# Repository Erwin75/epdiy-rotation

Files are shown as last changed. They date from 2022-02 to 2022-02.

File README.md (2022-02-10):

  

EPDiy E-Paper Driver
=======================================

EPDiy is a driver board which talks to affordable E-Paper (or E-Ink) screens, which are usually sold as replacement screens for E-Book readers. Why are they interesting?

* Easy on the eyes and paper-like aesthetics
* No power consumption when not updating
* Sunlight-readable

Ready-made DIY modules for this size and with 4bpp (16 Grayscale) color support are currently quite expensive. This project uses Kindle replacement screens, which are available for 20$ (small) / 30$ (large) on ebay!

The EPDiy driver board targets multiple E-Paper displays. As the driving method for all matrix-based E-ink displays seems to be more or less the same, only the right connector and timings are needed. The EPDiy PCB v5 features 33pin, 34pin and a 39pin connectors, which allow to drive the following display types: ED097OC4, ED060SC4, ED097TC2, ED060SC7. For the full list of supported displays, refer to the table below.

Revision 5 of the board is optimized for the use with LiPo batteries, featuring a LiPo charger and ultra-low deep sleep current.

This project supports a driver for the ESP-IDF and Arduino. For installation instructions, please refer to the [documentation](https://epdiy.readthedocs.io/en/latest/getting_started.html#getting-your-board).

Building It
-----------

If you want to build a board right now, there are two possible routes:

 - Use the new v6 PCB (`hardware/epaper-breakout/gerbers_v6.zip`). 
   **So far, I only tested a prototype of it. The gerbers only contain fixes for powering from battery, but have not yet been ordered with.**
   **If you have tested them, please let me know!**
   The BOM is available at (`hardware/epaper-breakout/BOM.csv`).
   Positioning files for SMT assembly are available at (`hardware/epaper-breakout/gerbers/epaper-breakout-top-pos.csv`). 
   Please double check the part positioning and Rotation with your assembly service!
   More information on the order process and where to find parts is in the [documentation](https://epdiy.readthedocs.io/en/latest/getting_started.html#getting-your-board).
 
   Make sure to select the `V6` board revision in `idf.py menuconfig` when building the examples.
 
 - Use the old v5 PCB (`hardware/epaper-breakout/gerbers_v5.zip`).  
   This is the last board using the LT1945 booster.
   Make sure to select the `V5` board revision in `idf.py menuconfig` when building the examples.

Gettings Started
----------------

For instructions and more information visit the [documentation](https://epdiy.readthedocs.io/en/latest/getting_started.html)!

Join the Discussion
----------------

 -  Matrix Community: +epdiy:matrix.vroland.de
 - Slack: See badge
Displays
--------

|Name|Size|Resolution|Compatible|Connector|Pin count|Compatible since pcb version|Notes
| --: | --: | --: | --: | --: | --: |--: |--: |
|ED060SC4|6"|800 x 600|yes, tested|FH26W-39S-0.3SHW(60)|39|v2|
|ED097OC4|9.7"|1200 x 825|yes, tested|XF2M-3315-1A|33|V2|Cheap, inferior contrast
|ED097TC2|9.7"|1200 x 825|yes, tested|XF2M-3315-1A|33|V2|Slightly higher price, better contrast
|ED097OC1|9.7"|1200 x 825|yes (should work)|XF2M-3315-1A|33|V2|Cheap, inferior performance
|ED047TC1|4.7"|960 x 540|yes, tested|40-pin|40|LILYGO 4.7" EPD|Supported only by 4.7" e-paper board by LILYGO
|ED052TC2|5.2"|960 x 540|yes, tested|40-pin|40|LILYGO 4.7" EPD|Supported only by 4.7" e-paper board by LILYGO
| ED050SC5 | 5" | 600 x 800 | yes, tested | THD0510-33CL-GF | 33 | v5 | 
| ED050SC3 | 5" | 600 x 800 | yes (should work) | THD0510-33CL-GF | 33 | v5 | 
|ED133UT2|13.3"|1600 x 1200|yes, tested|adapter board|39|V2|Adapter Board required, also PENG133D
|ED060XC3|6"|758 x 1024|yes, tested|THD0515-34CL-SN|34|V5|Cheapest, good contrast and resolution
|ED060XD4|6"|758 x 1024|yes, tested|THD0515-34CL-SN|34|V5|
|ED060XC5|6"|758 x 1024|yes (should work as ED060XC3)|THD0515-34CL-SN|34|V5|
|ED060XD6|6"|758 x 1024|yes (should work as ED060XC3)|THD0515-34CL-SN|34|V5|
|ED060XH2|6"|758 x 1024|yes (should work as ED060XC3)|THD0515-34CL-SN|34|V5|
|ED060XC9|6"|758 x 1024|yes (should work as ED060XC3)|THD0515-34CL-SN|34|V5|
|ED060KD1|6"|1072 x 1448|yes (should work as ED060XC3)|THD0515-34CL-SN|34|V5|
|ED060KC1|6"|1072 x 1448|yes (should work as ED060XC3)|THD0515-34CL-SN|34|V5|
|ED060SCF|6"|600 x 800|yes, tested|THD0515-34CL-SN|34|V5|Different flex cable shape
|ED060SCN|6"|600 x 800|yes (should work as ED060XC3)|THD0515-34CL-SN|34|V5|Different flex cable shape
|ED060SCP|6"|600 x 800|yes (should work as ED060XC3)|THD0515-34CL-SN|34|V5|Different flex cable shape
| ED060SC7 | 6" | 600 x 800 | yes (should work) | AXT334124 | 34 | v5 |connector dropped in v6
| ED060SCG | 6" | 600 x 800 | yes (should work) | AXT334124 | 34 | v5 |connector dropped in v6
| ED060SCE | 6" | 600 x 800 | yes (should work) | AXT334124 | 34 | v5 |connector dropped in v6
| ED060SCM | 6" | 600 x 800 | yes (should work) | AXT334124 | 34 | v5 |connector dropped in v6
| ED060SCT | 6" | 600 x 800 | yes, tested | AXT334124 | 34 | v5 |connector dropped in v6

Troubleshooting
---------------

The following list is compiled from past experiences and GitHub issues:
 * **The displayed image displays only part of the image.** Make sure to select the correct display type as described [here](https://epdiy.readthedocs.io/en/latest/getting_started.html#selecting-a-display-type).
 * **The existing image fades / darkens when updating a partial screen region.** Make sure the VCOM voltage is [calibrated](https://epdiy.readthedocs.io/en/latest/getting_started.html#calibrate-vcom) for your specific display.
 * **The second third of the image is replaced with the last third.** This seems to be a timing issue we could not yet quite figure out the reason for. For a workarround or suggestions please [join the discussion](https://github.com/vroland/epdiy/issues/15).
 * **The ESP does not boot correctly when external periperals are connected.** Make sure not to pull GPIO12 high during boot, as it is a strapping pin internal voltage selection (https://github.com/vroland/epdiy/issues/17).
 
More on E-Paper Displays
------------------------

 * List of E-Paper devices and their screens: https://e-ink-reader.ru/chg_dsp_en.php (thanks, @mcer12)
 * Reverse engineering of display pins, possible starting point for alternative drivers: https://linux-sunxi.org/PocketBook_Touch_Lux_3 (thanks, @mcer12)
 * Reverse engineering and explanation on driving EPDs: http://essentialscrap.com/eink/index.html
 * Earlier take on driving 6" EPDs with an ESP32, basis of original power circuit: http://spritesmods.com/?art=einkdisplay&page=1
 * Related Hackaday projects: https://hackaday.io/project/21607 https://hackaday.io/project/11537

If you know any other useful resources or have suggestions, please comment on #31!

Hackaday Project
----------------

For more details, see the project page on Hackaday: https://hackaday.io/project/168193-epdiy-976-e-paper-controller

demo image
board front

Licenses
--------

The weather example is Copyright (c) David Bird 2018 (except for minor modifications). Please refer to `examples/weather/README.md` for details.

The board and schematic are licensed under a  <a rel="license" href="https://creativecommons.org/licenses/by-sa/4.0/">Creative Commons Attribution-ShareAlike 4.0 International License</a>.

Firmware and remaining examples are licensed under the terms of the GNU GPL version 3.
Utilities are licensed under the terms of the MIT license.

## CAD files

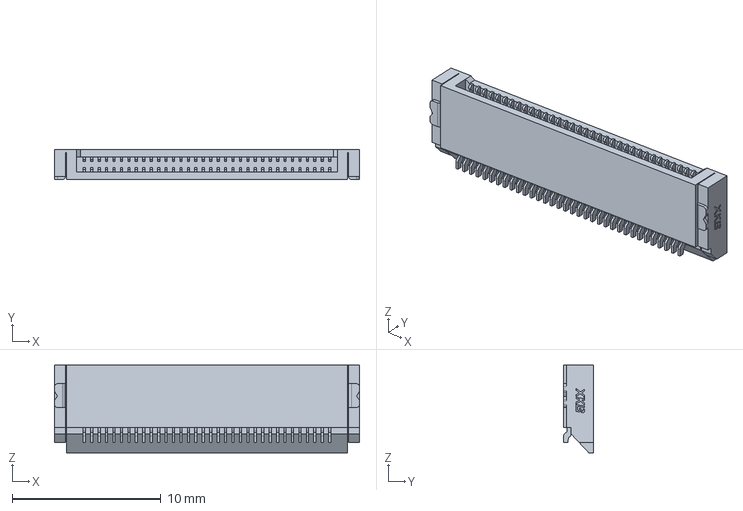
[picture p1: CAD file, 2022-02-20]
hardware/epaper-breakout/3dmodels/x05a20h34x_FPC.stp
20.5 x 2.00 x 5.90 mm

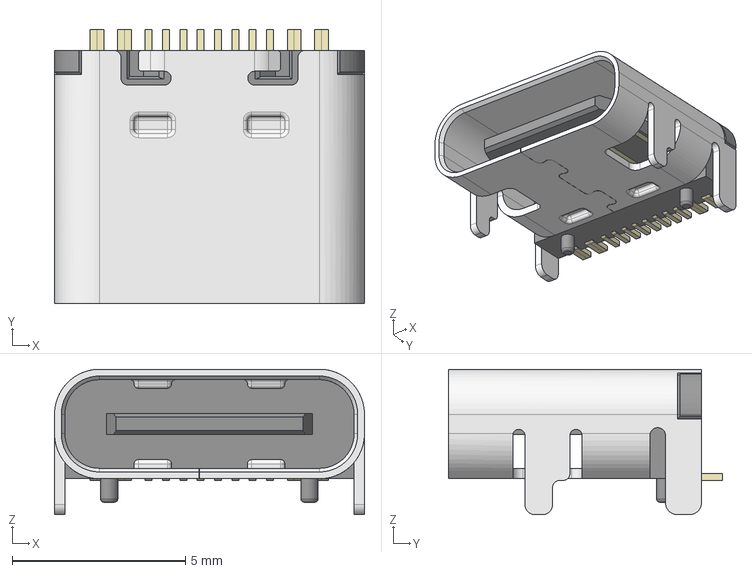
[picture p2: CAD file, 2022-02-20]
hardware/epaper-breakout/3dmodels/HRO_TYPE-C-31-M-12.step
8.95 x 7.90 x 4.20 mm

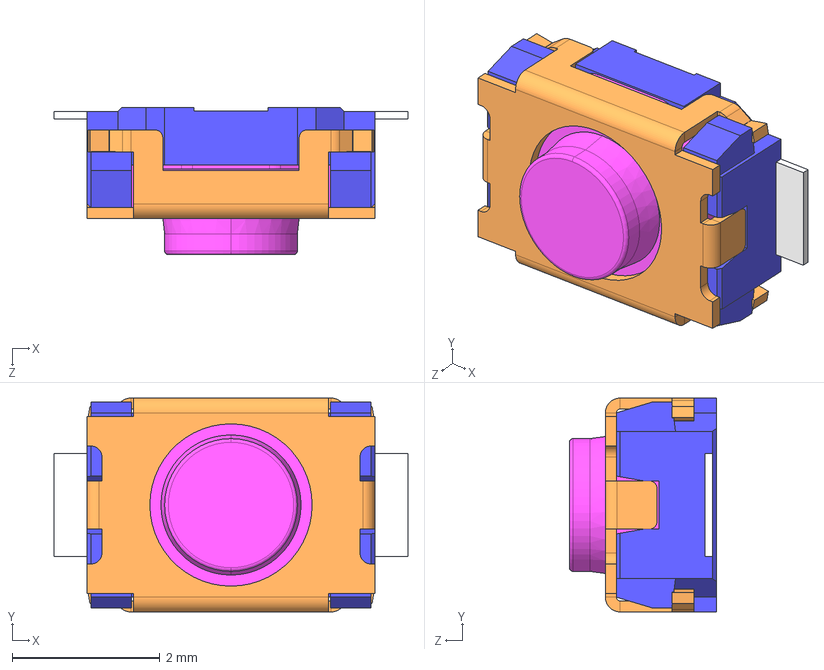
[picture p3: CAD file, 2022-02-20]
hardware/epaper-breakout/3dmodels/SKRKAH.STEP
4.80 x 2.90 x 2.00 mm

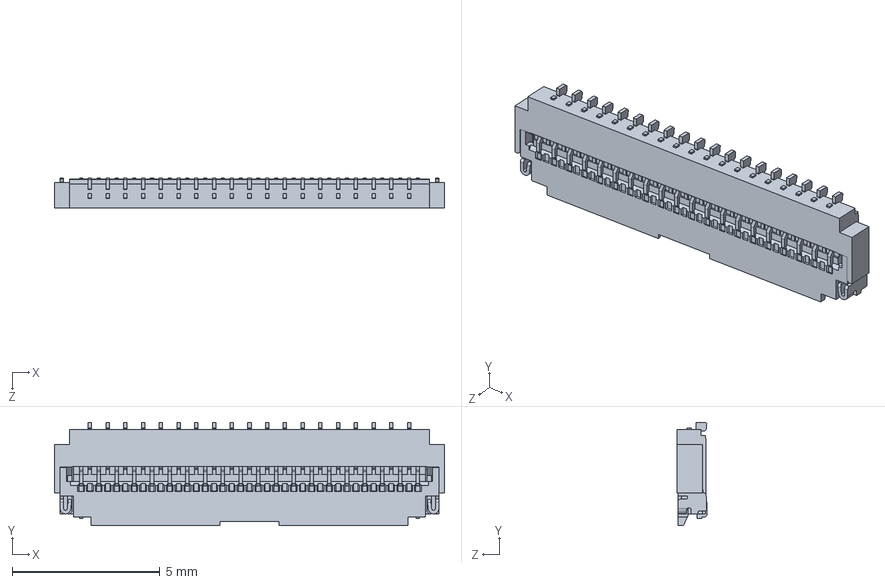
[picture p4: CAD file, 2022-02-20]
hardware/epaper-breakout/3dmodels/Hirose_39pin_FPC.STEP
13.2 x 3.50 x 1.00 mm

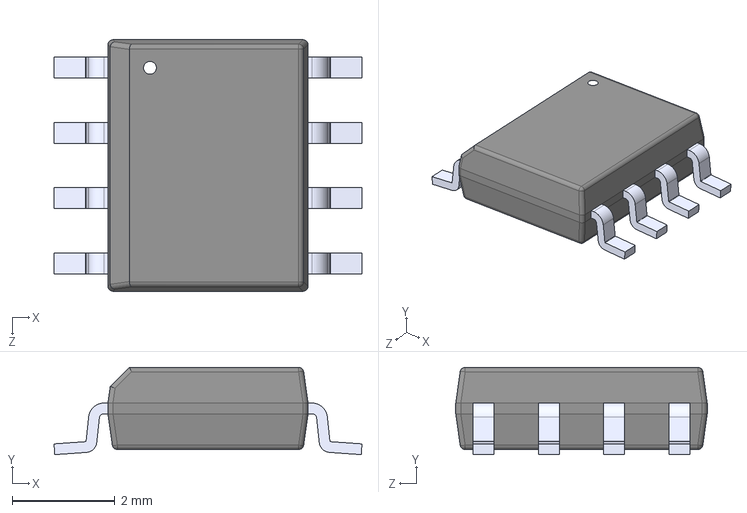
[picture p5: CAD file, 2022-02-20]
hardware/epaper-breakout/3dmodels/TP4056.step
6.00 x 1.70 x 4.90 mm

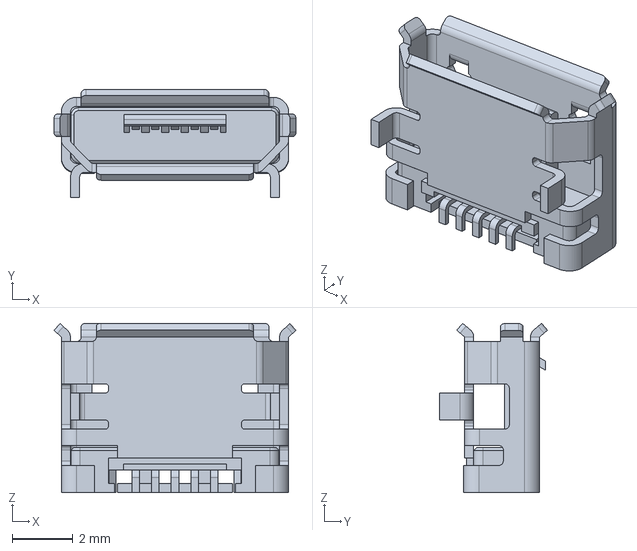
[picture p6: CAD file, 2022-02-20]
hardware/epaper-breakout/3dmodels/MicroUSB-2013499-1-f-3d.stp
8.00 x 3.57 x 5.60 mm

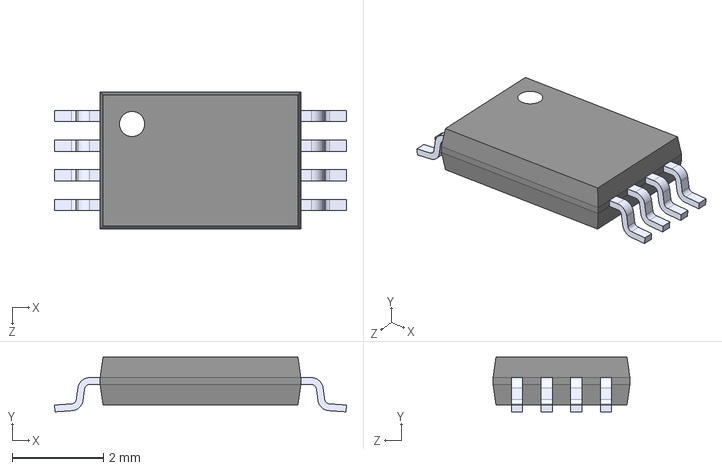
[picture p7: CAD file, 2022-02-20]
hardware/epaper-breakout/3dmodels/tps2113apwr.step
6.40 x 1.20 x 3.00 mm

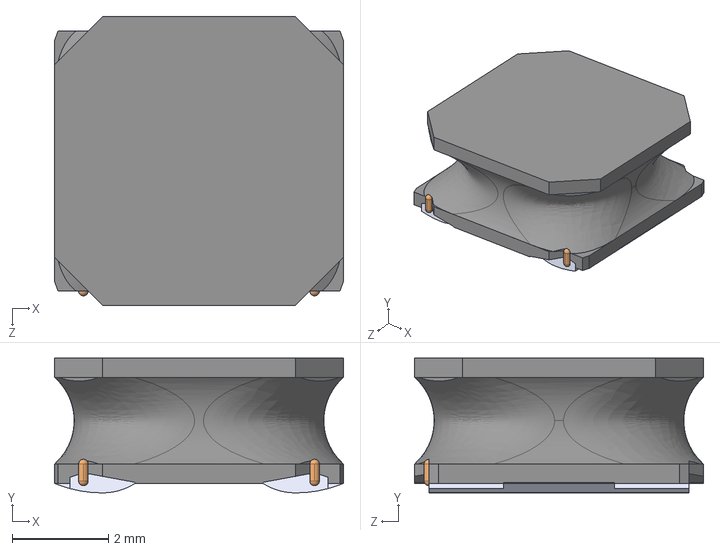
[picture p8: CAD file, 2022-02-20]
hardware/epaper-breakout/3dmodels/L-40xx.STEP
6.00 x 2.80 x 6.00 mm

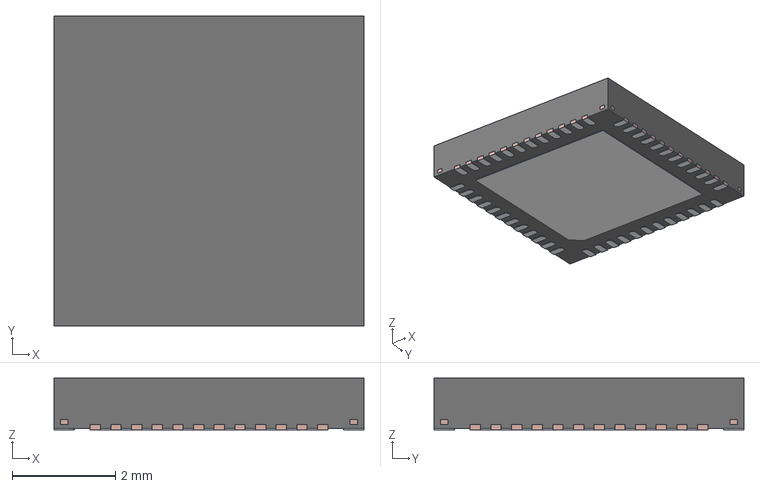
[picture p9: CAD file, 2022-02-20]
hardware/epaper-breakout/3dmodels/TPS65185.step
6.00 x 6.00 x 1.00 mm
FRAME

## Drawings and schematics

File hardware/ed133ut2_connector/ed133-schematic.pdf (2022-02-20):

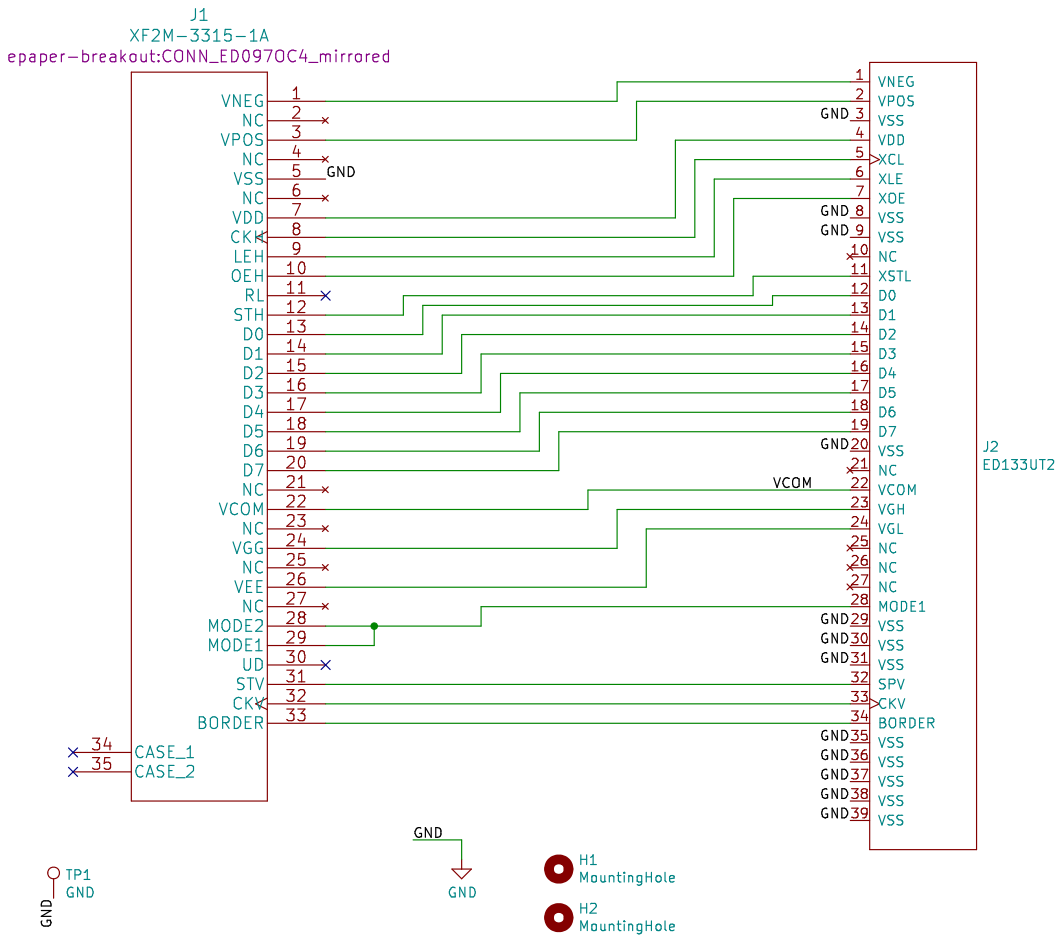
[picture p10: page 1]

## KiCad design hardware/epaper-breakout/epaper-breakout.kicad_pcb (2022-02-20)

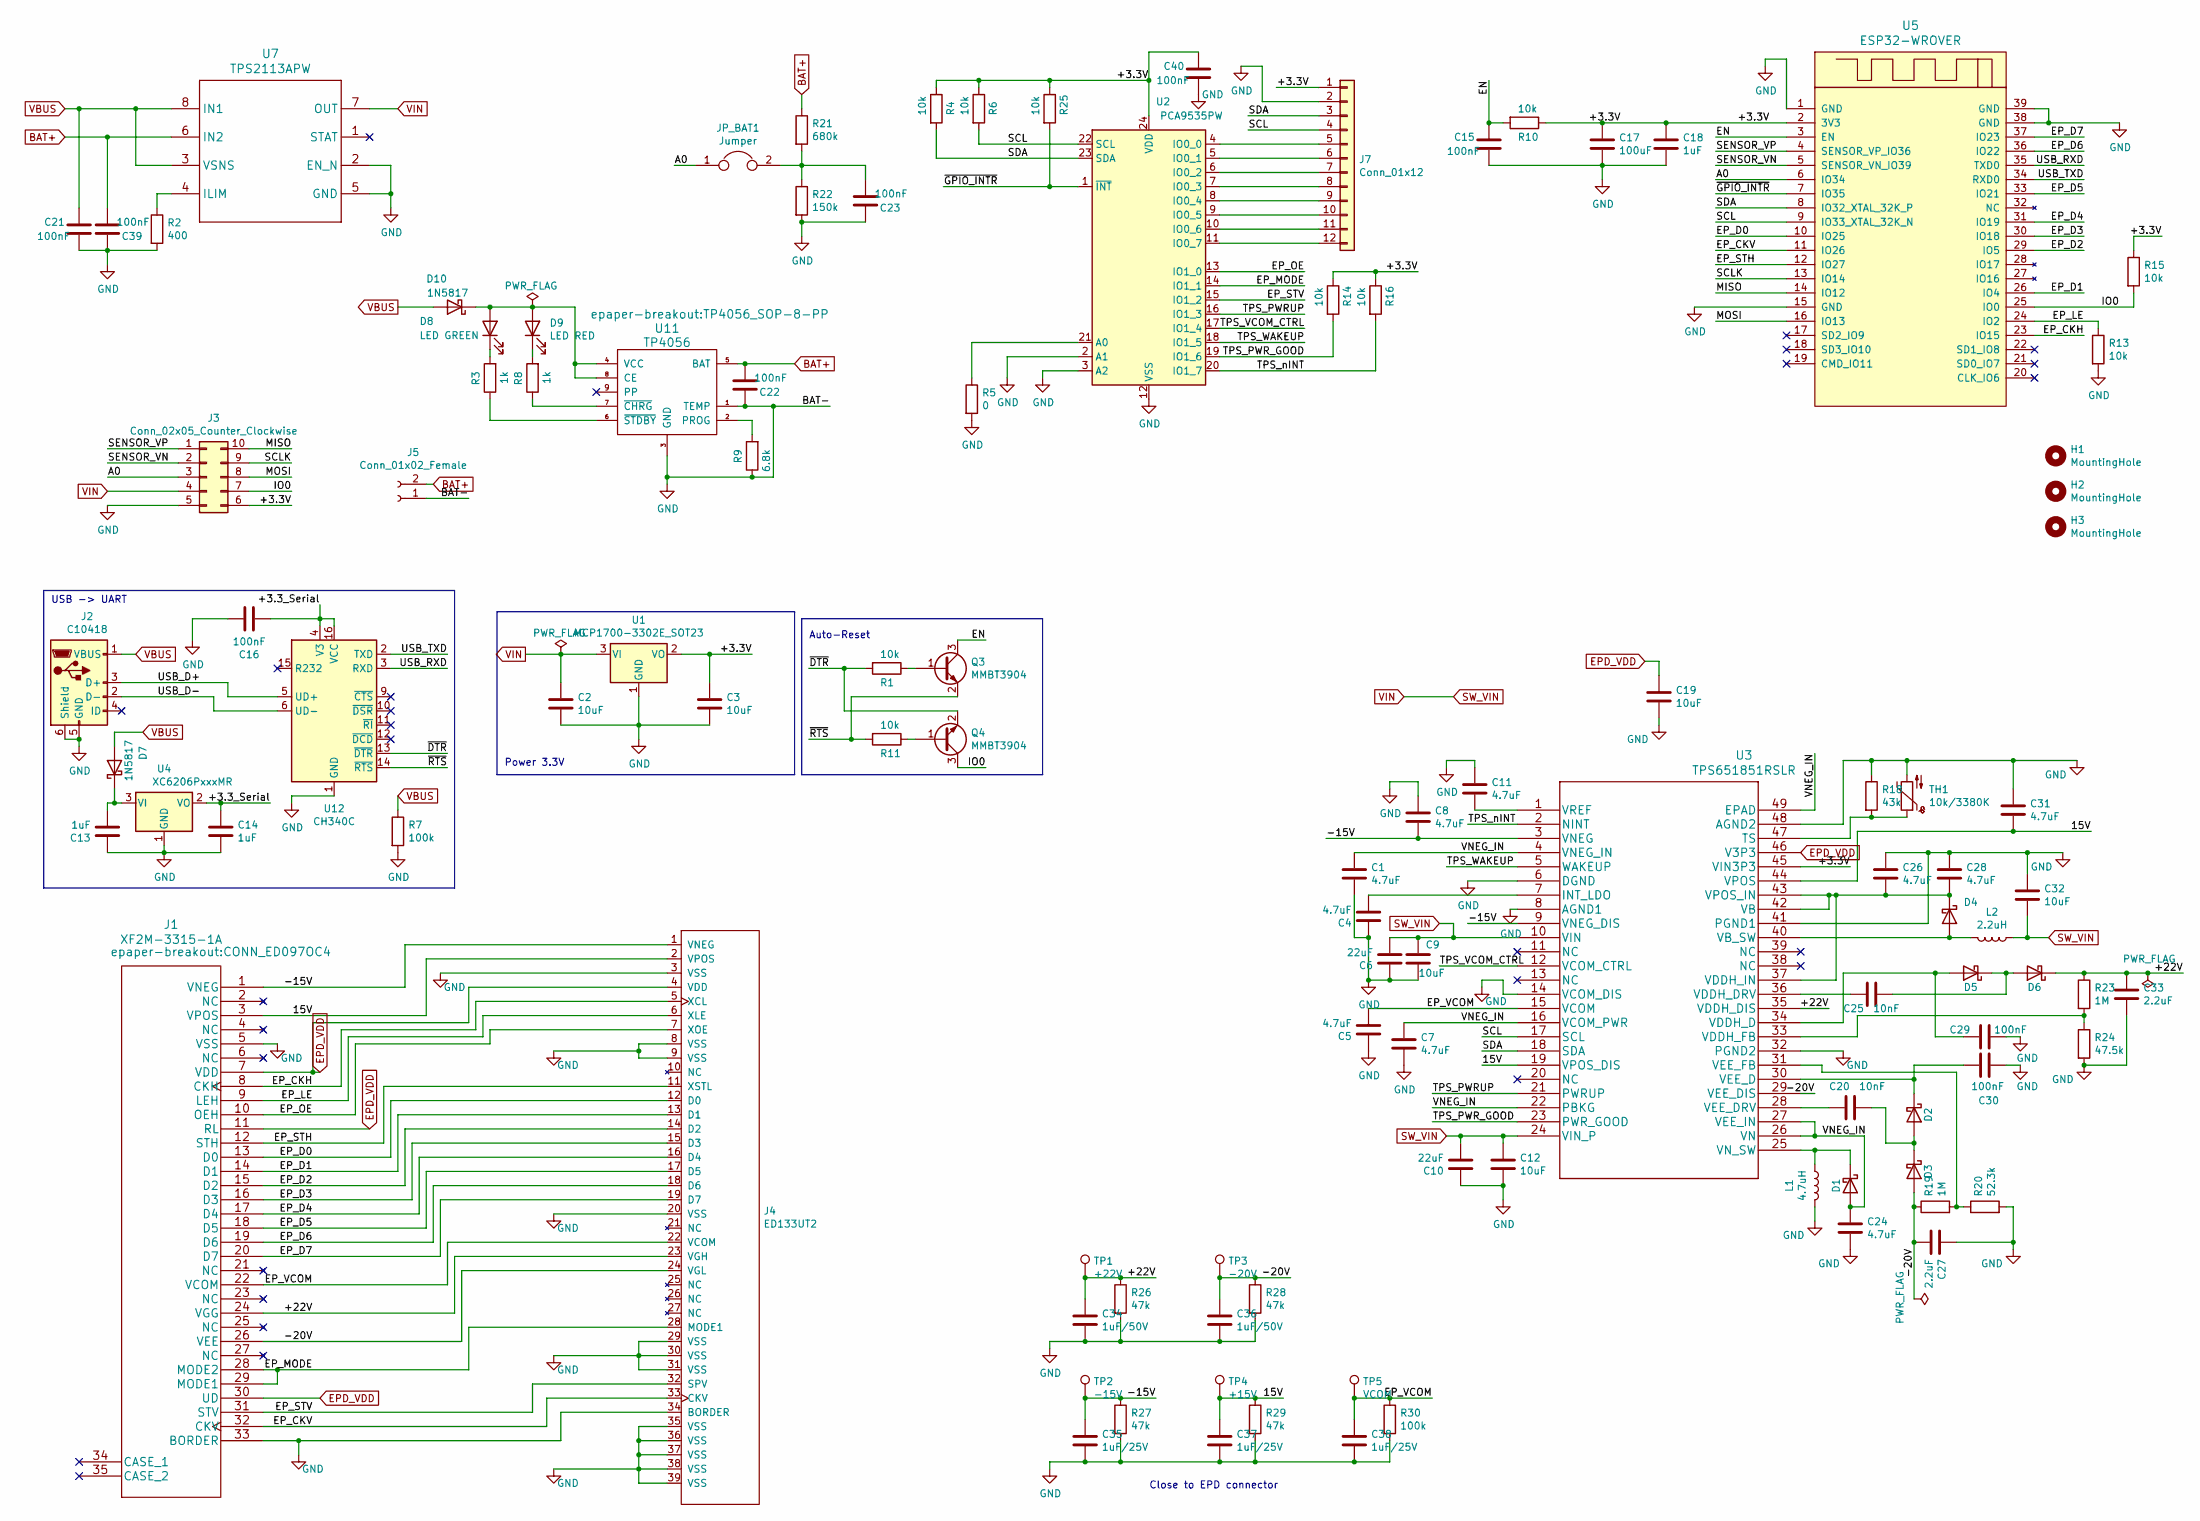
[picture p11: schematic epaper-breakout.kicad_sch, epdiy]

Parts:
C1, C4, C5, C7, C8, C11, C24, C26, C28, C31: 4.7uF; C_0805_2012Metric; LCSC C1779
C2, C3, C9, C12, C32: 10uF; C_0805_2012Metric; LCSC C15850
C6, C10: 22uF; C_0805_2012Metric; LCSC C45783
C13, C14, C18: 1uF; C_0805_2012Metric; LCSC C28323
C15, C16, C21, C22, C23, C29, C30, C39, C40: 100nF; C_0805_2012Metric; LCSC C49678
C17: 100uF; CP_EIA-3528-15_AVX-H; LCSC C16133
C19: 10uF; C_0805_2012Metric; LCSC C19702
C20, C25: 10nF; C_0805_2012Metric; LCSC C1710
C27, C33: 2.2uF; C_0805_2012Metric; LCSC C49217
C34, C36: 1uF/50V; C_1206_3216Metric; LCSC C1848
C35, C37, C38: 1uF/25V; C_0805_2012Metric; LCSC C28323
D1, D2, D3, D4, D5, D6: MBR0540; D_SOD-123; LCSC C21353
D7, D10: 1N5817; D_SOD-123; LCSC C8598
D8: LED GREEN; LED_0805_2012Metric; LCSC C2297
D9: LED RED; LED_0805_2012Metric; LCSC C84256
H1, H2, H3: MountingHole; MountingHole_2.2mm_M2
J1: XF2M-3315-1A; CONN_ED097OC4; LCSC C231420
J2: C10418; USB_Micro-B_A01SB141B1-067; LCSC C10418
J3: Conn_02x05_Counter_Clockwise; PinHeader_2x05_P2.54mm_Vertical
J4: ED133UT2; HRS_FH26W-39S-0.3SHW(60)
J5: Conn_01x02_Female; PinHeader_1x02_P2.54mm_Vertical
J7: Conn_01x12; PinHeader_2x06_P2.54mm_Vertical
JP_BAT1: Jumper; SolderJumper-2_P1.3mm_Bridged2Bar_RoundedPad1.0x1.5mm
L1: 4.7uH; L_Taiyo-Yuden_NR-50xx_HandSoldering; LCSC C222947
L2: 2.2uH; L_Taiyo-Yuden_NR-40xx_HandSoldering; LCSC C92959
Q3, Q4: MMBT3904; SOT-23; LCSC C20526
R1, R4, R6, R10, R11, R13, R14, R15, R16, R25: 10k; R_0603_1608Metric; LCSC C25804
R2: 400; R_0603_1608Metric; LCSC C23151
R3, R8: 1k; R_0603_1608Metric; LCSC C21190
R5: 0; R_0603_1608Metric
R7, R30: 100k; R_0603_1608Metric; LCSC C25803
R9: 6.8k; R_0603_1608Metric; LCSC C23212
R18: 43k; R_0603_1608Metric; LCSC C23172
R19, R23: 1M; R_0603_1608Metric; LCSC C22935
R20: 52.3k; R_0603_1608Metric; LCSC C23196
R21: 680k; R_0603_1608Metric; LCSC C25822
R22: 150k; R_0603_1608Metric; LCSC C22807
R24: 47.5k; R_0603_1608Metric; LCSC C25819
R26, R27, R28, R29: 47k; R_0603_1608Metric; LCSC C25819
TH1: 10k/3380K; R_0603_1608Metric; LCSC C76589
TP1: +22V; TestPoint_Pad_D2.5mm
TP2: -15V; TestPoint_Pad_D2.5mm
TP3: -20V; TestPoint_Pad_D2.5mm
TP4: +15V; TestPoint_Pad_D2.5mm
TP5: VCOM; TestPoint_Pad_D2.5mm
U1: MCP1700-3302E_SOT23; SOT-23; LCSC C39051
U2: PCA9535PW; TSSOP-24_4.4x7.8mm_P0.65mm; LCSC C255606
U3: TPS651851RSLR; LCSC C139292
U4: XC6206PxxxMR; SOT-23; LCSC C5446
U5: ESP32-WROVER; LCSC C503591
U7: TPS2113APW; LCSC C130052
U11: TP4056; TP4056_SOP-8-PP; LCSC C16581
U12: CH340C; SOIC-16_3.9x9.9mm_P1.27mm; LCSC C84681

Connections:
/15V: C31.2, C37.1, J1.3 (VPOS), J4.2 (VPOS), R29.1, TP4.1, U3.19 (VPOS_DIS), U3.44 (VPOS)
/+3.3V: C3.2, C17.1, C18.2, C40.1, J3.6, J7.1, R4.1, R6.1, R10.1, R14.1, R15.1, R16.1, R25.1, U1.2 (VO), U2.24 (VDD), U3.45 (VIN3P3), U5.2 (3V3)
/+3.3_Serial: C14.2, C16.1, U4.2 (VO), U12.4 (V3), U12.16 (VCC)
/+22V: C33.1, C34.1, D6.1 (K), J1.24 (VGG), J4.23 (VGH), R23.1, R26.1, TP1.1, U3.35 (VDDH_DIS)
/-15V: C8.2, C35.1, J1.1 (VNEG), J4.1 (VNEG), R27.1, TP2.1, U3.3 (VNEG), U3.9 (VNEG_DIS)
/-20V: C27.2, C36.1, D3.2 (A), J1.26 (VEE), J4.24 (VGL), R19.1, R28.1, TP3.1, U3.29 (VEE_DIS)
/A0: J3.3, JP_BAT1.1, U5.6 (IO34)
/EN: C15.1, Q3.3 (C), R10.2, U5.3 (EN)
/EP_CKH: J1.8 (CKH), J4.5 (XCL), U5.23 (IO15)
/EP_CKV: J1.32 (CKV), J4.33 (CKV), U5.11 (IO26)
/EP_D0: J1.13 (D0), J4.12 (D0), U5.10 (IO25)
/EP_D1: J1.14 (D1), J4.13 (D1), U5.26 (IO4)
/EP_D2: J1.15 (D2), J4.14 (D2), U5.29 (IO5)
/EP_D3: J1.16 (D3), J4.15 (D3), U5.30 (IO18)
/EP_D4: J1.17 (D4), J4.16 (D4), U5.31 (IO19)
/EP_D5: J1.18 (D5), J4.17 (D5), U5.33 (IO21)
/EP_D6: J1.19 (D6), J4.18 (D6), U5.36 (IO22)
/EP_D7: J1.20 (D7), J4.19 (D7), U5.37 (IO23)
/EP_LE: J1.9 (LEH), J4.6 (XLE), R13.1, U5.24 (IO2)
/EP_MODE: J1.28 (MODE2), J1.29 (MODE1), J4.28 (MODE1), U2.14 (IO1_1)
/EP_OE: J1.10 (OEH), J4.7 (XOE), U2.13 (IO1_0)
/EP_STH: J1.12 (STH), J4.11 (XSTL), U5.12 (IO27)
/EP_STV: J1.31 (STV), J4.32 (SPV), U2.15 (IO1_2)
/EP_VCOM: C5.2, C38.1, J1.22 (VCOM), J4.22 (VCOM), R30.1, TP5.1, U3.15 (VCOM)
/IO0: J3.7, Q4.3 (C), R15.2, U5.25 (IO0)
/MISO: J3.10, U5.14 (IO12)
/MOSI: J3.8, U5.16 (IO13)
/SCL: J7.4, R6.2, U2.22 (SCL), U3.17 (SCL), U5.9 (IO33_XTAL_32K_N)
/SCLK: J3.9, U5.13 (IO14)
/SDA: J7.3, R4.2, U2.23 (SDA), U3.18 (SDA), U5.8 (IO32_XTAL_32K_P)
/SENSOR_VN: J3.2, U5.5 (SENSOR_VN_IO39)
/SENSOR_VP: J3.1, U5.4 (SENSOR_VP_IO36)
/TPS_PWRUP: U2.16 (IO1_3), U3.21 (PWRUP)
/TPS_PWR_GOOD: R14.2, U2.19 (IO1_6), U3.23 (PWR_GOOD)
/TPS_VCOM_CTRL: U2.17 (IO1_4), U3.12 (VCOM_CTRL)
/TPS_WAKEUP: U2.18 (IO1_5), U3.5 (WAKEUP)
/TPS_nINT: R16.2, U2.20 (IO1_7), U3.2 (NINT)
/USB_D+: J2.3 (D+), U12.5 (UD+)
/USB_D-: J2.2 (D-), U12.6 (UD-)
/USB_RXD: U5.35 (TXD0), U12.3 (RXD)
/USB_TXD: U5.34 (RXD0), U12.2 (TXD)
/VNEG_IN: C1.1, C7.1, C24.1, D1.2 (A), U3.4 (VNEG_IN), U3.16 (VCOM_PWR), U3.22 (PBKG), U3.26 (VN), U3.27 (VEE_IN), U3.49 (EPAD)
/~DTR: Q4.2 (E), R1.2, U12.13 (~DTR)
/~GPIO_INTR: R25.2, U2.1 (~INT), U5.7 (IO35)
/~RTS: Q3.2 (E), R11.2, U12.14 (~RTS)
BAT+: C22.2, C39.2, J5.2, R21.1, U7.6 (IN2), U11.5 (BAT)
EPD_VDD: C19.1, J1.7 (VDD), J1.11 (RL), J1.30 (UD), J4.4 (VDD), U3.46 (V3P3)
GND: C1.2, C2.1, C3.1, C4.1, C5.1, C6.1, C7.2, C8.1, C9.2, C10.1, C11.1, C12.2, C13.2, C14.1, C15.2, C16.2, C17.2, C18.1, C19.2, C21.2, C22.1, C23.1, C24.2, C26.1, C27.1, C28.1, C29.1, C30.2, C31.1, C32.1, C33.2, C34.2, C35.2, C36.2, C37.2, C38.2, C39.1, C40.2, J1.5 (VSS), J1.33 (BORDER), J2.5 (GND), J2.6 (Shield), J3.5, J4.3 (VSS), J4.8 (VSS), J4.9 (VSS), J4.20 (VSS), J4.29 (VSS), J4.30 (VSS), J4.31 (VSS), J4.34 (BORDER), J4.35 (VSS), J4.36 (VSS), J4.37 (VSS), J4.38 (VSS), J4.39 (VSS), J5.1, J7.2, L1.2, R2.2, R5.2, R7.2, R9.1, R13.2, R18.1, R20.2, R22.2, R24.2, R26.2, R27.2, R28.2, R29.2, R30.2, TH1.2, U1.1 (GND), U2.2 (A1), U2.3 (A2), U2.12 (VSS), U3.6 (DGND), U3.8 (AGND1), U3.14 (VCOM_DIS), U3.32 (PGND2), U3.41 (PGND1), U3.48 (AGND2), U4.1 (GND), U5.1 (GND), U5.15 (GND), U5.38 (GND), U5.39 (GND), U7.2 (EN_N), U7.5 (GND), U11.1 (TEMP), U11.3 (GND), U12.1 (GND)
unnamed: C4.2, U3.7 (INT_LDO)
unnamed: C11.2, U3.1 (VREF)
unnamed: C13.1, D7.1 (K), U4.3 (VI)
unnamed: C20.1, D2.2 (A), D3.1 (K)
unnamed: C20.2, U3.28 (VEE_DRV)
unnamed: C23.2, JP_BAT1.2, R21.2, R22.1
unnamed: C25.1, D5.1 (K), D6.2 (A)
unnamed: C25.2, U3.36 (VDDH_DRV)
unnamed: C26.2, C28.2, D4.1 (K), U3.37 (VDDH_IN), U3.42 (VB), U3.43 (VPOS_IN)
unnamed: C29.2, D5.2 (A), U3.34 (VDDH_D)
unnamed: C30.1, D2.1 (K), U3.30 (VEE_D)
unnamed: D1.1 (K), L1.1, U3.25 (VN_SW)
unnamed: D4.2 (A), L2.2, U3.40 (VB_SW)
unnamed: D8.1 (K), R3.2
unnamed: D9.1 (K), R8.2
unnamed: D8.2 (A), D9.2 (A), D10.1 (K), U11.4 (VCC), U11.8 (CE)
unnamed: J7.5, U2.4 (IO0_0)
unnamed: J7.6, U2.5 (IO0_1)
unnamed: J7.7, U2.6 (IO0_2)
unnamed: J7.8, U2.7 (IO0_3)
unnamed: J7.9, U2.8 (IO0_4)
unnamed: J7.10, U2.9 (IO0_5)
unnamed: J7.11, U2.10 (IO0_6)
unnamed: J7.12, U2.11 (IO0_7)
unnamed: Q3.1 (B), R1.1
unnamed: Q4.1 (B), R11.1
unnamed: R2.1, U7.4 (ILIM)
unnamed: R3.1, U11.6 (~STDBY)
unnamed: R5.1, U2.21 (A0)
unnamed: R8.1, U11.7 (~CHRG)
unnamed: R9.2, U11.2 (PROG)
unnamed: R18.2, TH1.1, U3.47 (TS)
unnamed: R19.2, R20.1, U3.31 (VEE_FB)
unnamed: R23.2, R24.1, U3.33 (VDDH_FB)
SW_VIN: C2.2, C6.2, C9.1, C10.2, C12.1, C32.2, J3.4, L2.1, U1.3 (VI), U3.10 (VIN), U3.24 (VIN_P), U7.7 (OUT)
VBUS: C21.1, D7.2 (A), D10.2 (A), J2.1 (VBUS), R7.1, U7.3 (VSNS), U7.8 (IN1)

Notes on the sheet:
Power 3.3V
USB -> UART
Auto-Reset
Close to EPD connector

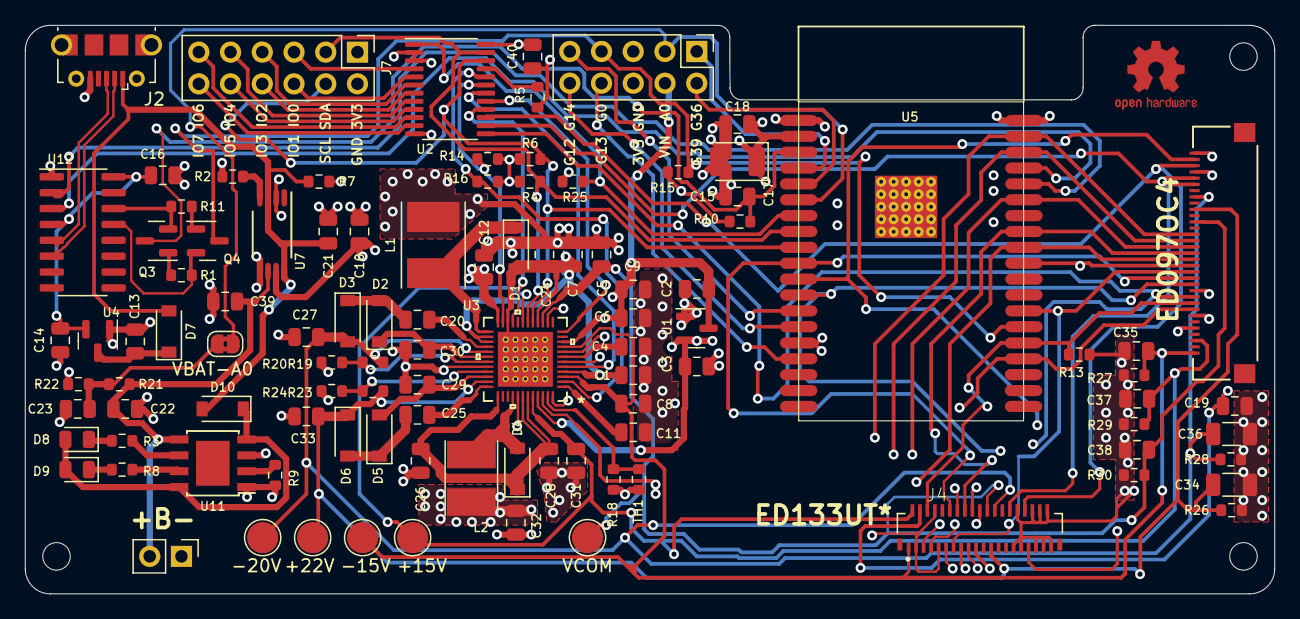
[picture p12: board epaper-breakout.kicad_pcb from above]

Board: 4 copper layers, 100.0 x 45.5 mm, 107 parts (1 on the bottom side), 84 nets.

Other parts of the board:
CC: Symbol_CreativeCommons_SilkScreenTop_Type2_Big

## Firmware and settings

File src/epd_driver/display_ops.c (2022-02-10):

#include "display_ops.h"
#include "epd_driver.h"
#include "esp_timer.h"
#include "esp_log.h"
#include "i2s_data_bus.h"
#include "rmt_pulse.h"
#include "freertos/FreeRTOS.h"
#include "freertos/task.h"

#include "xtensa/core-macros.h"

#if defined(CONFIG_EPD_BOARD_REVISION_V2_V3) || defined(CONFIG_EPD_BOARD_REVISION_LILYGO_T5_47)
#include "config_reg_v2.h"
#else
#if defined(CONFIG_EPD_BOARD_REVISION_V4) || defined(CONFIG_EPD_BOARD_REVISION_V5)
#include "config_reg_v4.h"
#else
#if defined(CONFIG_EPD_BOARD_REVISION_V6)
#include "config_reg_v6.h"
#else
#error "unknown revision"
#endif
#endif
#endif

static epd_config_register_t config_reg;

/*
 * Write bits directly using the registers.
 * Won't work for some pins (>= 32).
 */
inline static void fast_gpio_set_hi(gpio_num_t gpio_num) {
  GPIO.out_w1ts = (1 << gpio_num);
}

inline static void fast_gpio_set_lo(gpio_num_t gpio_num) {
  GPIO.out_w1tc = (1 << gpio_num);
}

void IRAM_ATTR busy_delay(uint32_t cycles) {
  volatile unsigned long counts = XTHAL_GET_CCOUNT() + cycles;
  while (XTHAL_GET_CCOUNT() < counts) {
  };
}


#if !defined(CONFIG_EPD_BOARD_REVISION_V6)
inline static void IRAM_ATTR push_cfg_bit(bool bit) {
  gpio_set_level(CFG_CLK, 0);
  if (bit) {
    gpio_set_level(CFG_DATA, 1);
  } else {
    gpio_set_level(CFG_DATA, 0);
  }
  gpio_set_level(CFG_CLK, 1);
}
#endif

void epd_i2s_lines_setup(uint32_t epd_row_width) {
  // Setup I2S
  i2s_bus_config i2s_config;
  // add an offset off dummy bytes to allow for enough timing headroom
  i2s_config.epd_row_width = epd_row_width + 32;
  i2s_config.clock = CKH;
  i2s_config.start_pulse = STH;
  i2s_config.data_0 = D0;
  i2s_config.data_1 = D1;
  i2s_config.data_2 = D2;
  i2s_config.data_3 = D3;
  i2s_config.data_4 = D4;
  i2s_config.data_5 = D5;
  i2s_config.data_6 = D6;
  i2s_config.data_7 = D7;

  i2s_bus_init(&i2s_config);
}

void epd_i2s_lines_down() {
  gpio_num_t DATA_BUS[] = {D6, D7, D4, D5, D2, D3, D0, D1, STH, CKH};
  for (uint8_t pin = 0; pin < 10; pin++) {
    gpio_set_direction(DATA_BUS[pin], GPIO_MODE_INPUT);
  }
}

void epd_base_init(uint32_t epd_row_width) {


#if defined(CONFIG_EPD_BOARD_REVISION_V6)
  i2c_config_t conf;
  conf.mode = I2C_MODE_MASTER;
  conf.sda_io_num = CFG_SDA;
  conf.scl_io_num = CFG_SCL;
  conf.sda_pullup_en = GPIO_PULLUP_ENABLE;
  conf.scl_pullup_en = GPIO_PULLUP_ENABLE;
  conf.master.clk_speed = 400000;
  conf.clk_flags = I2C_SCLK_SRC_FLAG_FOR_NOMAL;
  ESP_ERROR_CHECK(i2c_param_config(EPDIY_I2C_PORT, &conf));

  ESP_ERROR_CHECK(i2c_driver_install(EPDIY_I2C_PORT, I2C_MODE_MASTER, 0, 0, 0));

  config_reg.port = EPDIY_I2C_PORT;
#else
  /* Power Control Output/Off */
  PIN_FUNC_SELECT(GPIO_PIN_MUX_REG[CFG_DATA], PIN_FUNC_GPIO);
  PIN_FUNC_SELECT(GPIO_PIN_MUX_REG[CFG_CLK], PIN_FUNC_GPIO);
  PIN_FUNC_SELECT(GPIO_PIN_MUX_REG[CFG_STR], PIN_FUNC_GPIO);
  gpio_set_direction(CFG_DATA, GPIO_MODE_OUTPUT);
  gpio_set_direction(CFG_CLK, GPIO_MODE_OUTPUT);
  gpio_set_direction(CFG_STR, GPIO_MODE_OUTPUT);
  fast_gpio_set_lo(CFG_STR);
#endif

  config_reg_init(&config_reg);

#if defined(CONFIG_EPD_BOARD_REVISION_V4) || defined(CONFIG_EPD_BOARD_REVISION_V5) || defined(CONFIG_EPD_BOARD_REVISION_V6)
  // use latch pin as GPIO
  PIN_FUNC_SELECT(GPIO_PIN_MUX_REG[V4_LATCH_ENABLE], PIN_FUNC_GPIO);
  ESP_ERROR_CHECK(gpio_set_direction(V4_LATCH_ENABLE, GPIO_MODE_OUTPUT));
  gpio_set_level(V4_LATCH_ENABLE, 0);
#endif

  push_cfg(&config_reg);

  epd_i2s_lines_setup(EPD_WIDTH);

  rmt_pulse_init(CKV);
}

void epd_poweron() {
  cfg_poweron(&config_reg);
  #if defined(CONFIG_EPD_BOARD_REVISION_LILYGO_T5_47)
  epd_i2s_lines_setup(EPD_WIDTH);
  #endif
}

void epd_poweroff() {
  cfg_poweroff(&config_reg);
  #if defined(CONFIG_EPD_BOARD_REVISION_LILYGO_T5_47)
  epd_i2s_lines_down();
  #endif
}

void epd_base_deinit(){
  epd_poweroff();
  i2s_deinit();

#if defined(CONFIG_EPD_BOARD_REVISION_V6)
  cfg_deinit(&config_reg);
  i2c_driver_delete(EPDIY_I2C_PORT);
#else
  config_reg.ep_stv = false;
  config_reg.ep_mode = false;
  config_reg.ep_output_enable = false;
  push_cfg(&config_reg);
#endif
}

void epd_start_frame() {
  while (i2s_is_busy() || rmt_busy()) {
  };
  config_reg.ep_mode = true;
  push_cfg(&config_reg);

  pulse_ckv_us(1, 1, true);

  // This is very timing-sensitive!
  config_reg.ep_stv = false;
  push_cfg(&config_reg);
  //busy_delay(240);
  pulse_ckv_us(1000, 100, false);
  config_reg.ep_stv = true;
  push_cfg(&config_reg);
  //pulse_ckv_us(0, 10, true);
  pulse_ckv_us(1, 1, true);
  pulse_ckv_us(1, 1, true);
  pulse_ckv_us(1, 1, true);
  pulse_ckv_us(1, 1, true);

  config_reg.ep_output_enable = true;
  push_cfg(&config_reg);
}

static inline void latch_row() {
#if defined(CONFIG_EPD_BOARD_REVISION_V2_V3) || defined(CONFIG_EPD_BOARD_REVISION_LILYGO_T5_47)
  config_reg.ep_latch_enable = true;
  push_cfg(&config_reg);

  config_reg.ep_latch_enable = false;
  push_cfg(&config_reg);
#else
#if defined(CONFIG_EPD_BOARD_REVISION_V4) || defined(CONFIG_EPD_BOARD_REVISION_V5) || defined(CONFIG_EPD_BOARD_REVISION_V6)
  fast_gpio_set_hi(V4_LATCH_ENABLE);
  fast_gpio_set_lo(V4_LATCH_ENABLE);
#else
#error "unknown revision"
#endif
#endif
}

void IRAM_ATTR epd_skip() {
#if defined(CONFIG_EPD_DISPLAY_TYPE_ED097TC2) ||                               \
    defined(CONFIG_EPD_DISPLAY_TYPE_ED133UT2)
  pulse_ckv_ticks(5, 5, false);
#else
  // According to the spec, the OC4 maximum CKV frequency is 200kHz.
  pulse_ckv_ticks(45, 5, false);
#endif
}

void IRAM_ATTR epd_output_row(uint32_t output_time_dus) {

  while (i2s_is_busy() || rmt_busy()) {
  };

  fast_gpio_set_hi(STH);

  latch_row();

#if defined(CONFIG_EPD_DISPLAY_TYPE_ED097TC2) ||                               \
    defined(CONFIG_EPD_DISPLAY_TYPE_ED133UT2)
  pulse_ckv_ticks(output_time_dus, 1, false);
#else
  pulse_ckv_ticks(output_time_dus, 50, false);
#endif

  i2s_start_line_output();
  i2s_switch_buffer();
}

void epd_end_frame() {
  config_reg.ep_stv = false;
  push_cfg(&config_reg);
  pulse_ckv_us(1, 1, true);
  pulse_ckv_us(1, 1, true);
  pulse_ckv_us(1, 1, true);
  pulse_ckv_us(1, 1, true);
  pulse_ckv_us(1, 1, true);
  config_reg.ep_mode = false;
  push_cfg(&config_reg);
  pulse_ckv_us(0, 10, true);
  config_reg.ep_output_enable = false;
  push_cfg(&config_reg);
  pulse_ckv_us(1, 1, true);
  pulse_ckv_us(1, 1, true);
  pulse_ckv_us(1, 1, true);
}

void IRAM_ATTR epd_switch_buffer() { i2s_switch_buffer(); }
uint8_t IRAM_ATTR *epd_get_current_buffer() {
  return (uint8_t *)i2s_get_current_buffer();
};

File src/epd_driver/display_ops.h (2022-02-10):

#pragma once

#include "driver/gpio.h"

#if defined(CONFIG_EPD_BOARD_REVISION_V5) || defined(CONFIG_EPD_BOARD_REVISION_V6)
#define D7 GPIO_NUM_23
#define D6 GPIO_NUM_22
#define D5 GPIO_NUM_21
#define D4 GPIO_NUM_19
#define D3 GPIO_NUM_18
#define D2 GPIO_NUM_5
#define D1 GPIO_NUM_4
#define D0 GPIO_NUM_25

/* Control Lines */
#define CKV GPIO_NUM_26
#define STH GPIO_NUM_27

#define V4_LATCH_ENABLE GPIO_NUM_2

/* Edges */
#define CKH GPIO_NUM_15

#if defined(CONFIG_EPD_BOARD_REVISION_V5)
/* Config Reggister Control */
#define CFG_DATA GPIO_NUM_33
#define CFG_CLK GPIO_NUM_32
#define CFG_STR GPIO_NUM_0
#endif
#if defined(CONFIG_EPD_BOARD_REVISION_V6)
#define CFG_SCL GPIO_NUM_33
#define CFG_SDA GPIO_NUM_32
#define CFG_INTR GPIO_NUM_35

#define EPDIY_I2C_PORT I2C_NUM_0
#endif

#else
#define D7 GPIO_NUM_22
#define D6 GPIO_NUM_21
#define D5 GPIO_NUM_27
#define D4 GPIO_NUM_2
#if defined(CONFIG_EPD_BOARD_REVISION_LILYGO_T5_47)
#define D3 GPIO_NUM_19
#else
#define D3 GPIO_NUM_0
#endif
#define D2 GPIO_NUM_4
#define D1 GPIO_NUM_32
#define D0 GPIO_NUM_33

#define CFG_DATA GPIO_NUM_23
#define CFG_CLK GPIO_NUM_18
#if defined(CONFIG_EPD_BOARD_REVISION_LILYGO_T5_47)
#define CFG_STR GPIO_NUM_0
#else
#define CFG_STR GPIO_NUM_19
#endif

/* Control Lines */
#define CKV GPIO_NUM_25
#define STH GPIO_NUM_26

#define V4_LATCH_ENABLE GPIO_NUM_15

/* Edges */
#define CKH GPIO_NUM_5

#endif

void epd_base_init(uint32_t epd_row_width);
void epd_base_deinit();
void epd_poweron();
void epd_poweroff();

/**
 * Start a draw cycle.
 */
void epd_start_frame();

/**
 * End a draw cycle.
 */
void epd_end_frame();

/**
 * Waits until all previously submitted data has been written.
 * Then, the following operations are initiated:
 *
 *  - Previously submitted data is latched to the output register.
 *  - The RMT peripheral is set up to pulse the vertical (gate) driver for
 *  `output_time_dus` / 10 microseconds.
 *  - The I2S peripheral starts transmission of the current buffer to
 *  the source driver.
 *  - The line buffers are switched.
 *
 * This sequence of operations allows for pipelining data preparation and
 * transfer, reducing total refresh times.
 */
void IRAM_ATTR epd_output_row(uint32_t output_time_dus);

/** Skip a row without writing to it. */
void IRAM_ATTR epd_skip();

/**
 * Get the currently writable line buffer.
 */
uint8_t IRAM_ATTR *epd_get_current_buffer();

/**
 * Switches front and back line buffer.
 * If the switched-to line buffer is currently in use,
 * this function blocks until transmission is done.
 */
void IRAM_ATTR epd_switch_buffer();

/**
 * Setup I2S data lines
 */
void epd_i2s_lines_setup(uint32_t epd_row_width);

/**
 * Put lines down since in some boards lines as output leak consumption
 */
void epd_i2s_lines_down();

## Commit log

2022-02-10 Add I2S lines down for Lilyo board https://github.com/vroland/epdiy/issues/136
    [display_ops.c, display_ops.h]
2022-02-20 Modified version adding 13.3 connector #4
    [HRO_TYPE-C-31-M-12.step, Hirose_39pin_FPC.STEP, L-40xx.STEP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]
2022-02-20 #4 Fix some DRC warnings
    [epaper-breakout.kicad_pcb]

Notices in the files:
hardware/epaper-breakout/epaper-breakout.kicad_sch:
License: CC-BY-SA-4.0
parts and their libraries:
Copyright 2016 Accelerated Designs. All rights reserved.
